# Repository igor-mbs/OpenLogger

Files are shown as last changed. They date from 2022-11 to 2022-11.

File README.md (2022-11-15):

# OpenLogger

<!--
![halley](halley.jpg)
"Halley's method"
=640x640
{width=320 height=240}
-->
<!-- <figure>
<img src="halley.jpg" alt="halley" width="32" style="width:200px;"/>
<figcaption>Halley's method</figcaption>
</figure> -->
<!-- <img src="halley.jpg" alt="halley" width="32"  style="width:320px;"/> -->
<!-- ![halley](halley.jpg =640x640) -->
<!-- ![halley](halley.jpg | width=640 ) -->
<!-- ![halley | width=50](halley.jpg) -->
<!-- ![PT485 =640x640](PT485.jpg) -->
<!-- <img src="PT485.jpg" alt="PT485" width="32" style="width:320px;"/> -->
<!-- ![PT485](PT485.jpg){width=50 height=50} -->
<!-- ![PT485](PT485.jpg){width=500px}
![PT485](PT485.jpg){width=50} -->
<!-- ![OpenLogger](pictures/OpenLogger.jpg){width=50%} -->
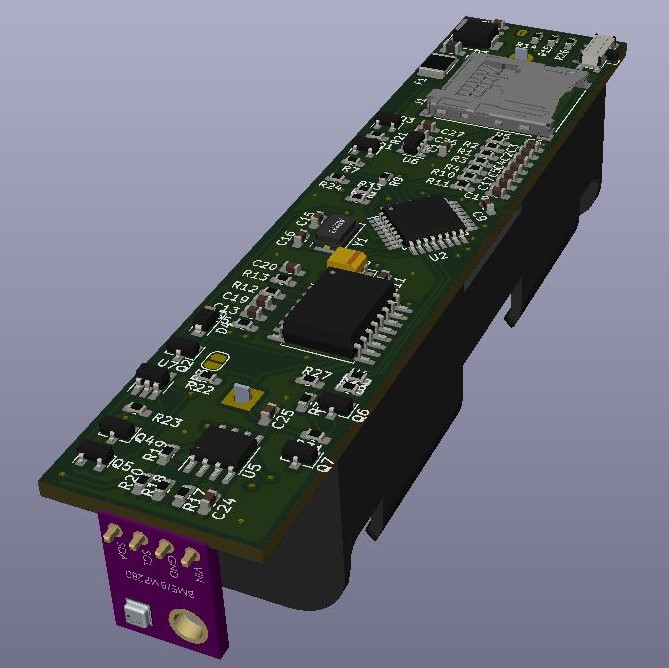
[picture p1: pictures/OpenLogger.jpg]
OpenLogger


## Introduction

&nbsp;&nbsp;&nbsp;&nbsp;This project is and Open-source portable datalogger based on the ATmega328p microcontroller.

&nbsp;&nbsp;&nbsp;&nbsp; The intent for this project is to provide an cost-friendly solution to support micro and small companies as well as the generall public. The project consists in an semi-modular data acquisition device capable of comunication with probes compatible with digital comunication, like I2C, SPI, serial and PWM.
Open-source portable datalogger project based on the ATmega328p microcontroller.

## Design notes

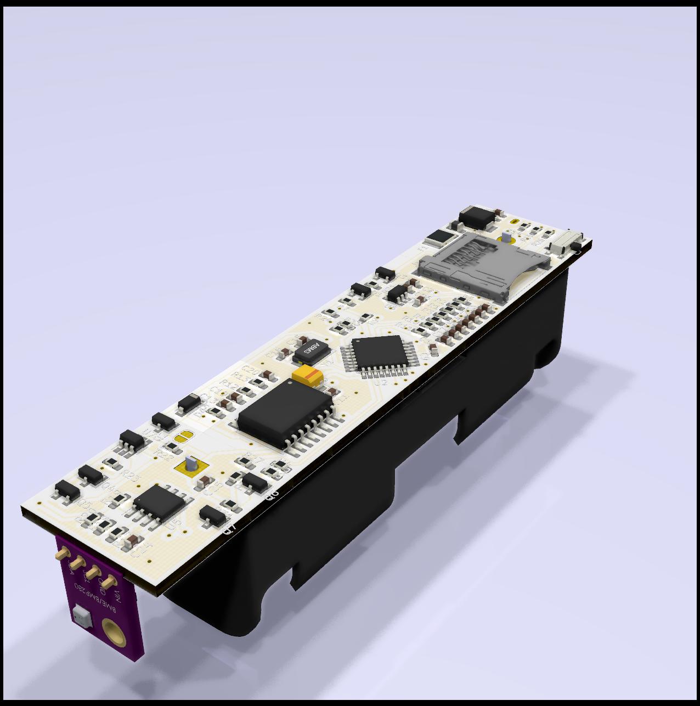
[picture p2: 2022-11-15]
hardware/electrical/TPH_Logge2r.jpg

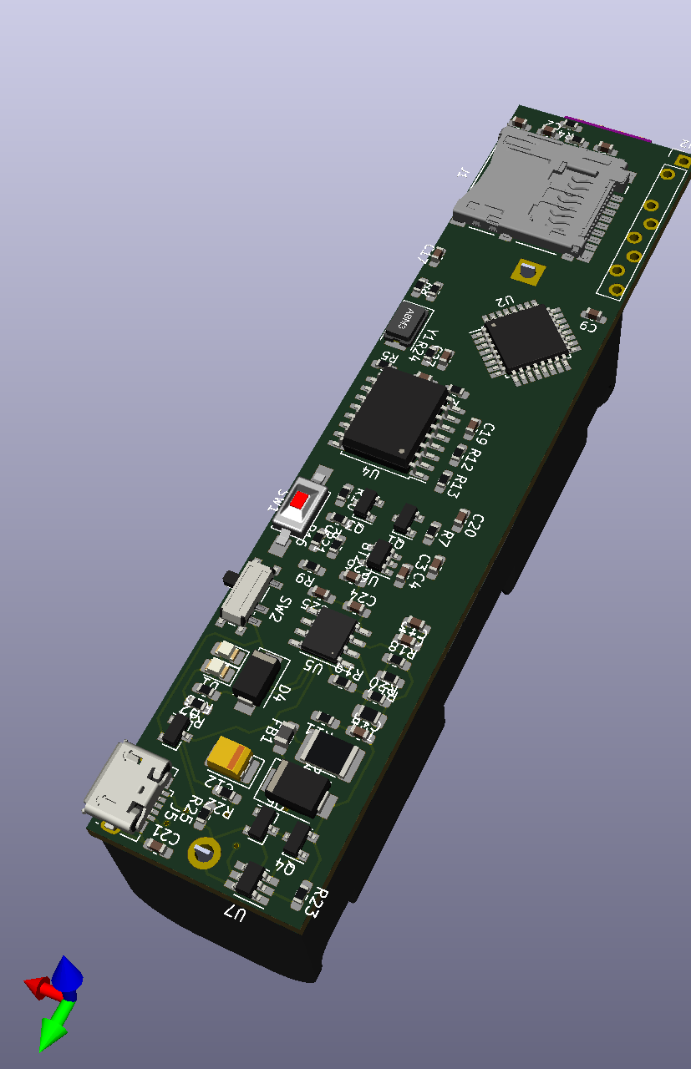
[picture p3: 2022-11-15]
hardware/electrical/TPH_Logger.png

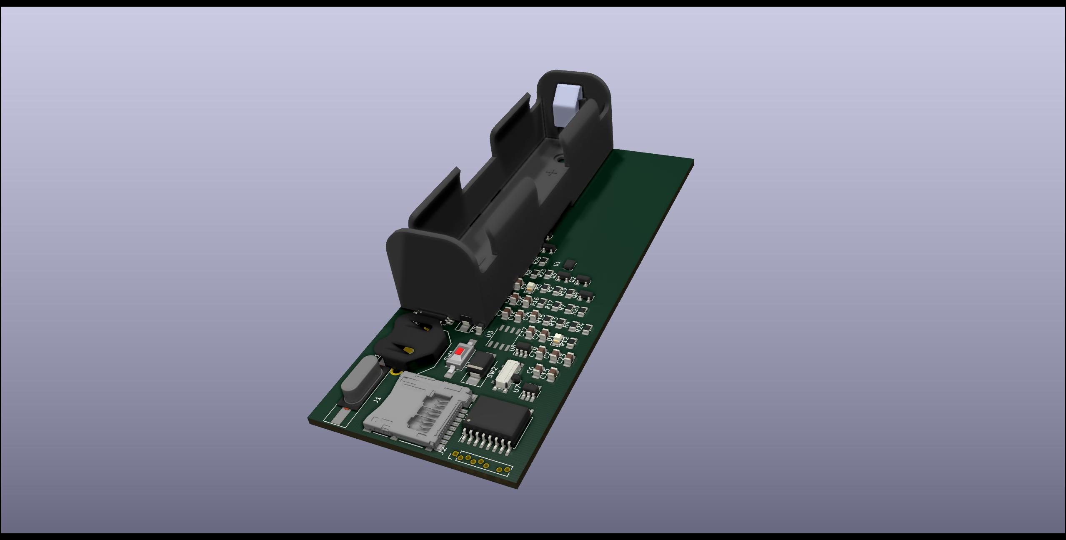
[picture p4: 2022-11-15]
hardware/electrical/TPH_Logger.jpg

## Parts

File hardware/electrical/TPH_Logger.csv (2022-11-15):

Id | Designator | Package | Quantity | Designation | Supplier and ref
1 | D3 | D_SMB | 1 | P6SMB6.8A
2 | SW2 | SW_SPDT_PCM12 | 1 | SW_SPDT
3 | C4,C2,C3,C5,C15,C16,C17,C18,C19,C20 | C_0603_1608Metric_Pad1.08x0.95mm_HandSolder | 10 | 12p
4 | R4,R1,R3,R2,R10,R11,R12,R13 | R_0603_1608Metric_Pad1.05x0.95mm_HandSolder | 8 | 3.3k
5 | D2,D1,D5 | LED_0805_2012Metric_Pad1.15x1.40mm_HandSolder | 3 | LED
6 | U6 | SOT-23-5 | 1 | LP2985-3.3
7 | U5 | SOP-8_3.9x4.9mm_P1.27mm | 1 | TP4056
8 | C12 | CP_EIA-3528-21_Kemet-B_Pad1.50x2.35mm_HandSolder | 1 | 4.7u
9 | F1 | R_1812_4532Metric_Pad1.30x3.40mm_HandSolder | 1 | MF-MSMF050/30
10 | FB1 | L_0805_2012Metric_Pad1.05x1.20mm_HandSolder | 1 | CB05YTYH600-1
11 | Q1,Q4,Q5,Q6 | SOT-23 | 4 | AO3400A
12 | Q2,Q3,Q7 | SOT-23 | 3 | AO3401A
13 | TH1 | R_0805_2012Metric_Pad1.15x1.40mm_HandSolder | 1 | 10k NTC
14 | U2 | TQFP-32_7x7mm_P0.8mm | 1 | ATmega328P-A
15 | U4 | SOIC-16W_7.5x10.3mm_P1.27mm | 1 | DS3231
16 | U7 | SOT-23-6_Handsoldering | 1 | DW01-P
17 | Y1 | Crystal_SMD_Abracon_ABM3-2Pin_5.0x3.2mm | 1 | 8M
18 | J5 | USB_Micro-B_GCT_USB3076-30-A | 1 | USB_B_Mini
19 | J3 | my_i2c_smd | 1 | External_I2C_0
20 | C6,C21,C1 | C_0603_1608Metric_Pad1.08x0.95mm_HandSolder | 3 | 1u
21 | C9,C11,C13 | C_0603_1608Metric_Pad1.08x0.95mm_HandSolder | 3 | 100n
22 | C24,C25 | C_0603_1608Metric_Pad1.08x0.95mm_HandSolder | 2 | 10u
23 | C26 | C_0603_1608Metric_Pad1.08x0.95mm_HandSolder | 1 | 10n
24 | C27 | C_0603_1608Metric_Pad1.08x0.95mm_HandSolder | 1 | 4.7u
25 | R5,R7,R9,R16,R21,R25,R29,R31 | R_0603_1608Metric_Pad1.05x0.95mm_HandSolder | 8 | 100k
26 | R14,R15,R22 | R_0603_1608Metric_Pad1.05x0.95mm_HandSolder | 3 | 470
27 | R17 | R_0603_1608Metric_Pad1.05x0.95mm_HandSolder | 1 | 2,2k
28 | R18,R26 | R_0603_1608Metric_Pad1.05x0.95mm_HandSolder | 2 | 330
29 | R19,R27,R30,R33 | R_0603_1608Metric_Pad1.05x0.95mm_HandSolder | 4 | 4.7k
30 | R20 | R_0603_1608Metric_Pad1.05x0.95mm_HandSolder | 1 | 82k
31 | R23 | R_0603_1608Metric_Pad1.05x0.95mm_HandSolder | 1 | 2K
32 | R24,R28 | R_0603_1608Metric_Pad1.05x0.95mm_HandSolder | 2 | 1k
33 | BT2 | 18650holder | 1 | 18650 Li-Ion (4.3-2.7V)
34 | JP3 | SolderJumper-2_P1.3mm_Open_RoundedPad1.0x1.5mm | 1 | SolderJumper
35 | J1 | molex-MicroSD-5027740891 | 1 | Micro_SD_Card
36 | R32 | R_0603_1608Metric_Pad1.05x0.95mm_HandSolder | 1 | 6.8k
37 | D4 | D_SOD-123 | 1 | MBR0530

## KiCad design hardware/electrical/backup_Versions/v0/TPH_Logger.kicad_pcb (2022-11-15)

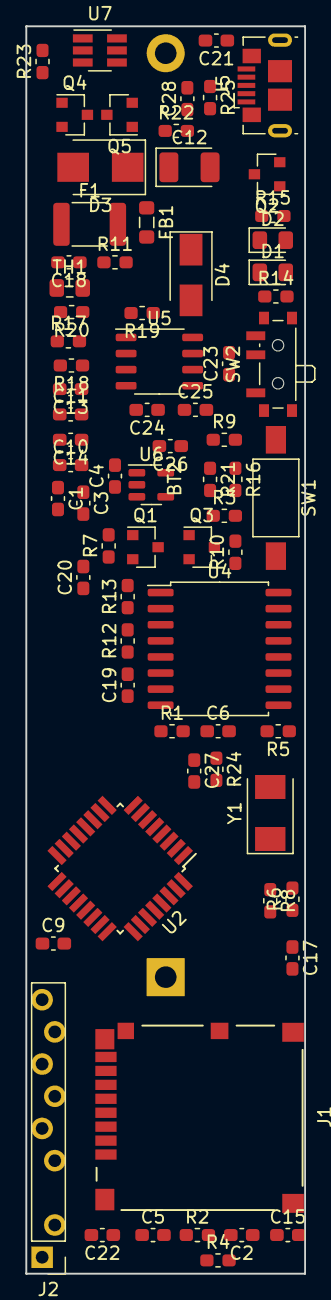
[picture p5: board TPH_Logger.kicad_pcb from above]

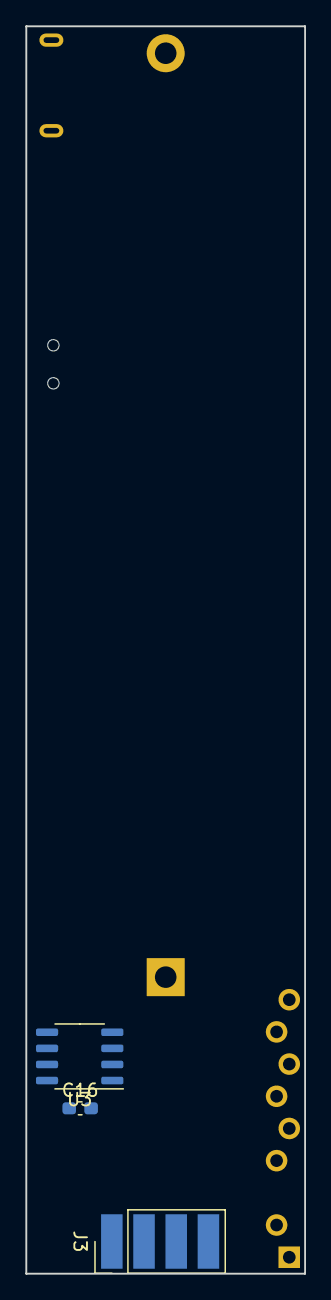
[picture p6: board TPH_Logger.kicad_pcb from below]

Board: 2 copper layers, 22.0 x 98.4 mm, 77 parts (3 on the bottom side), 44 nets, no tracks yet.

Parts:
BT2: 18650 Li-Ion (4.3-2.7V); 18650holder
C1, C9, C11, C13, C14, C28: 100n; C_0603_1608Metric_Pad1.08x0.95mm_HandSolder
C2, C3, C4, C5, C17, C18, C19, C20: 12p; C_0603_1608Metric_Pad1.08x0.95mm_HandSolder
C6, C21, C22: 1u; C_0603_1608Metric_Pad1.08x0.95mm_HandSolder
C10, C26: 10n; C_0603_1608Metric_Pad1.08x0.95mm_HandSolder
C12: 4.7u; CP_EIA-3528-21_Kemet-B_Pad1.50x2.35mm_HandSolder
C15, C16: 22p; C_0603_1608Metric_Pad1.08x0.95mm_HandSolder
C23, C27: 4.7u; C_0603_1608Metric_Pad1.08x0.95mm_HandSolder
C24, C25: 10u; C_0603_1608Metric_Pad1.08x0.95mm_HandSolder
D1, D2: LED; LED_0805_2012Metric_Pad1.15x1.40mm_HandSolder
D3: P6SMB6.8A; D_SMB
D4: MBRA340; D_SMA
F1: MF-MSMF050/30; R_1812_4532Metric_Pad1.30x3.40mm_HandSolder
FB1: CB05YTYH600-1; L_0805_2012Metric_Pad1.05x1.20mm_HandSolder
J1: Micro_SD_Card; molex-MicroSD-5027740891
J2: ICSP; Igor Prog
J3: External_I2C_0; my_i2c_smd
J5: USB_B_Mini; USB_Micro-B_GCT_USB3076-30-A
Q1, Q4, Q5: AO3400A; SOT-23
Q2, Q3: AO3401A; SOT-23
R1, R2, R3, R4, R10, R11, R12, R13: 3.3k; R_0603_1608Metric_Pad1.05x0.95mm_HandSolder
R5, R16, R25: 100k; R_0603_1608Metric_Pad1.05x0.95mm_HandSolder
R6, R24: 1k; R_0603_1608Metric_Pad1.05x0.95mm_HandSolder
R7, R9, R14, R15, R21: 10k; R_0603_1608Metric_Pad1.05x0.95mm_HandSolder
R8: 1K; R_0603_1608Metric_Pad1.05x0.95mm_HandSolder
R17: 2,2k; R_0603_1608Metric_Pad1.05x0.95mm_HandSolder
R18: 330; R_0603_1608Metric_Pad1.05x0.95mm_HandSolder
R19: 4.7k; R_0603_1608Metric_Pad1.05x0.95mm_HandSolder
R20: 82k; R_0603_1608Metric_Pad1.05x0.95mm_HandSolder
R22: 470; R_0603_1608Metric_Pad1.05x0.95mm_HandSolder
R23: 2K; R_0603_1608Metric_Pad1.05x0.95mm_HandSolder
SW1: SW_Push; SW_SPST_FSMSM
SW2: SW_SPDT; SW_SPDT_PCM12
TH1: 10k NTC; R_0805_2012Metric_Pad1.15x1.40mm_HandSolder
U2: ATmega328P-A; TQFP-32_7x7mm_P0.8mm
U3: M24C64; SO-8_3.9x4.9mm_P1.27mm
U4: DS3231; SOIC-16W_7.5x10.3mm_P1.27mm
U5: TP4056; SOP-8_3.9x4.9mm_P1.27mm
U6: LP2985-3.3; SOT-23-5
U7: DW01-P; SOT-23-6_Handsoldering
Y1: 8M; Crystal_SMD_Abracon_ABM3-2Pin_5.0x3.2mm

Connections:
32kHz: C20.1, R13.2, U2.9, U4.1
+3V3: C10.2, C11.2, C12.1, C13.1, C14.1, C27.1, J2.1, Q3.2, R12.2, R13.1, R21.1, U2.4, U2.6, U2.18, U4.2, U6.5
+18650: BT2.1, C25.2, C28.1, Q2.3, R22.2, U5.5
+USB: C22.2, C24.2, D4.2, F1.1, Q2.1, R14.1, R15.1, R19.1, R25.2, U5.4, U5.8
+VBus: C23.2, D4.1, Q2.2, SW2.3, U6.1
-18650: BT2.2, C28.2, Q5.2, R25.1, U7.6
-CR1220: C1.1, C2.1, C3.1, C4.1, C5.1, C6.1, C9.2, C10.1, C11.1, C12.2, C13.2, C14.2, C15.1, C16.1, C17.2, C18.2, C19.1, C20.2, C21.2, C22.1, C23.1, C24.1, C25.1, C26.2, C27.2, D3.2, J1.6, J2.4, J3.2, J5.5, Q1.2, Q4.2, R5.2, R7.1, R16.2, R18.2, R20.2, R23.1, SW1.2, SW2.1, TH1.1, U2.3, U2.5, U2.21, U3.1, U3.2, U3.4, U3.7, U4.5, U4.6, U4.7, U4.8, U4.9, U4.10, U4.11, U4.12, U4.13, U5.3, U6.2
CS_0: C5.2, J1.2, R4.1, U2.14
Log_supply: C1.2, J1.4, J3.1, Q3.3, R1.2, R2.2, R3.2, R4.2, R9.1, R10.2, R11.2, U3.8
Log_supply_control: R24.2, U2.10
MISO: C2.2, J1.7, J2.6, R1.1, U2.16
MOSI: C4.2, J1.3, J2.5, R3.1, U2.15
unnamed: C6.2, J1.9, R5.1
unnamed: C9.1, U2.20
unnamed: C15.2, U2.7, Y1.1
unnamed: C16.2, U2.8, Y1.2
unnamed: C21.1, J5.6, R16.1
unnamed: C26.1, U6.4
unnamed: D1.1, U5.6
unnamed: D1.2, R14.2
unnamed: D2.1, U5.7
unnamed: D2.2, R15.2
unnamed: D3.1, FB1.1, J5.1
unnamed: F1.2, FB1.2
unnamed: Q1.1, R7.2, R24.1
unnamed: Q1.3, Q3.1, R21.2
unnamed: Q4.1, U7.3
unnamed: Q4.3, Q5.3
unnamed: Q5.1, U7.1
unnamed: R6.1, U2.30
unnamed: R8.2, U2.31
unnamed: R17.1, U5.2
unnamed: R17.2, R18.1
unnamed: R19.2, R20.1, TH1.2, U5.1
unnamed: R22.1, U7.5
unnamed: R23.2, U7.2
unnamed: SW2.2, U6.3
RX: J2.2, R6.2
SCK: C3.2, J1.5, J2.7, R2.1, U2.17
SCL: C17.1, J3.3, R10.1, U2.28, U3.6, U4.16
SDA: C18.1, J3.4, R11.1, U2.27, U3.5, U4.15
TX: J2.3, R8.1
~INT~\SQW: C19.2, R12.1, U2.32, U4.3
~RESET: J2.8, R9.2, SW1.1, U2.29

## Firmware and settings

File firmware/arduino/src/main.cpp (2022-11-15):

#include <Arduino.h>
// Comms <---
#include <Wire.h>
#include <SPI.h>
#include <SD.h>
File myFile;
char sdname[] = "log.csv";

// Sensor <---
#include <Adafruit_Sensor.h>
#include <Adafruit_BME280.h>
#define SEALEVELPRESSURE_HPA (1013.25)
Adafruit_BME280 bme;
uint32_t value;
char arr[3];

// Power Saving <---
#include <LowPower.h> // https://github.com/rocketscream/Low-Power

// RTC <---
#include "RTClib.h"
RTC_DS3231 rtc;
//  const byte rtcPin = 0; // Interrupt Pin
const byte wakeUpPin = 2; // Interrupt Pin
// #define CLOCK_INTERRUPT_PIN 2

// Misc <---
float t;
float h;
float p;
float a;

void logData();

const byte ledPin = 15;
volatile byte state = LOW;
void interrupt1();

void setup() {//----------------------------------------------------------------------------------
  Wire.begin();        // join i2c bus (address optional for master)
  pinMode(ledPin, OUTPUT);
  
                          digitalWrite(ledPin, HIGH);
                          delay(250);
                          digitalWrite(ledPin, LOW);
                          delay(250);
                          digitalWrite(ledPin, HIGH);
                          delay(250);
                          digitalWrite(ledPin, LOW);


  // RTC setup <---
  rtc.begin();
  // if (! rtc.begin()) {
  //  // digitalWrite(ledPin, HIGH);
  //   while (1);
  // }
  //if (! rtc.isrunning()) {
 // if (rtc.lostPower()) {
    // Serial.println("RTC lost power!");
    // following line sets the RTC to the date & time this sketch was compiled
 //   rtc.adjust(DateTime(F(__DATE__), F(__TIME__)));
    // This line sets the RTC with an explicit date & time, for example to set
    // January 21, 2014 at 3am you would call:
    // rtc.adjust(DateTime(2014, 1, 21, 3, 0, 0));
 // }
  //we don't need the 32K Pin, so disable it

                      delay(250);
                      digitalWrite(ledPin, HIGH);
                      delay(250);
                      digitalWrite(ledPin, LOW);
                      
  
  rtc.disable32K();
  // set alarm 1, 2 flag to false (so alarm 1, 2 didn't happen so far)
  // if not done, this easily leads to problems, as both register aren't reset on reboot/recompile
  rtc.clearAlarm(1);
  //rtc.clearAlarm(2);
  // stop oscillating signals at SQW Pin
  // otherwise setAlarm1 will fail
  rtc.writeSqwPinMode(DS3231_OFF);
  // turn off alarm 2 (in case it isn't off already)
  // again, this isn't done at reboot, so a previously set alarm could easily go overlooked
  // rtc.disableAlarm(1);
  // //rtc.disableAlarm(2);
  rtc.setAlarm1(DateTime(0, 0, 0, 0, 0, 0), DS3231_A1_PerSecond);



  //MicroSD setup <---
  if (! SD.begin(10)) {
    while (1);
  }
  if (! SD.exists(sdname)){
    myFile = SD.open(sdname, FILE_WRITE);
    if (myFile) {
      myFile.print("Date"); myFile.print(";"); myFile.print("Temp_C"); myFile.print(";"); myFile.print("Hum_%"); myFile.print(";"); myFile.print("Pres_hPa"); myFile.print(";"); myFile.println("Alt_m");
      myFile.close(); 
    } else {
      digitalWrite(ledPin, HIGH);
      while (1);
    }
  }

  // Sensor setup <---
  if (!bme.begin(0x76)) {
    while (1);
  }
  
  // Interrupts setup <---
  pinMode(wakeUpPin, INPUT_PULLUP);
  attachInterrupt(digitalPinToInterrupt(wakeUpPin), interrupt1, FALLING); //Attach interrupt

  delay(500);
}//----------------------------------------------------------------------------------

void loop() {//----------------------------------------------------------------------------------
  
  if (state==true){
    logData();
    state=!state;
    digitalWrite(ledPin, state);
    rtc.clearAlarm(1);
  }
  //blink debug
  // digitalWrite(ledPin, state);

  // Rearm alarm <---
  // delay(1);
  // if(rtc.alarmFired(1)) {
  // rtc.clearAlarm(1);
  // };

  // Sleep <---
  LowPower.powerDown(SLEEP_FOREVER, ADC_OFF, BOD_OFF);
  
}//----------------------------------------------------------------------------------

void interrupt1() {
  state = !state;
  digitalWrite(ledPin, state);
}

void logData() {//----------------------------------------------------------------------------------
  // //Debug
  // Wire.beginTransmission(0x76);
  // Wire.write(0xFA);
  // Wire.endTransmission();
  // arr[0] = Wire.requestFrom(0x76, 3);
  // value = arr[0];
  // value <<= 8;
  // value |= arr[1];
  // value <<= 8;
  // value |= arr[2];
  // Serial.print("t: "); Serial.println(value);

  //Read sensor
  t = bme.readTemperature();
  h = bme.readHumidity();
  p = (bme.readPressure() / 100.0F);
  a = bme.readAltitude(SEALEVELPRESSURE_HPA);
  // if (isnan(t) || isnan(h) || isnan(p)) {
  //   Serial.println("Failed to read sensor");
  // }

  //Debug
  // Serial.println("");
  // Serial.print("t: "); Serial.println(t);
  // Serial.print("h: "); Serial.println(h);
  // Serial.print("p: "); Serial.println(p);
  // Serial.print("a: "); Serial.println(a);
  // Serial.flush();

  //Date
  DateTime now = rtc.now();

  // Logging <---
  myFile = SD.open(sdname, FILE_WRITE);
  if (myFile) {
    //Saving
    myFile.print(now.day(), DEC);
    myFile.print('/');
    myFile.print(now.month(), DEC);
    myFile.print('/');
    myFile.print(now.year(), DEC);
    myFile.print(' ');
    //myFile.print(" (");
    //myFile.print(daysOfTheWeek[now.dayOfTheWeek()]);
    //myFile.print(") ");
    myFile.print(now.hour(), DEC);
    myFile.print(':');
    myFile.print(now.minute(), DEC);
    myFile.print(':');
    myFile.print(now.second(), DEC);
    myFile.print(";");
    
    //Sensor
    if (isnan(t) || isnan(h) || isnan(p)) {
      myFile.println("Failed to read sensor;");
    }
    myFile.print(t);
    myFile.print(";");
    myFile.print(h);
    myFile.print(";");
    myFile.print(p);
    myFile.print(";");
    myFile.println(a);
    myFile.close();
  } else {
    // Serial.print("Error opening "); Serial.println(sdname); //If the file didn't open, print an error:
  }
  // Serial.print("Saved to "); Serial.println(sdname);

  // // Rearm alarm <---
  // delay(1);
  // if(rtc.alarmFired(1)) {
  // rtc.clearAlarm(1);
  // };
}//----------------------------------------------------------------------------------
